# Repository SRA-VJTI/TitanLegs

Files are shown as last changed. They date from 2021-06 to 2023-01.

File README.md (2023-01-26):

# TitanLegs

## Schematics
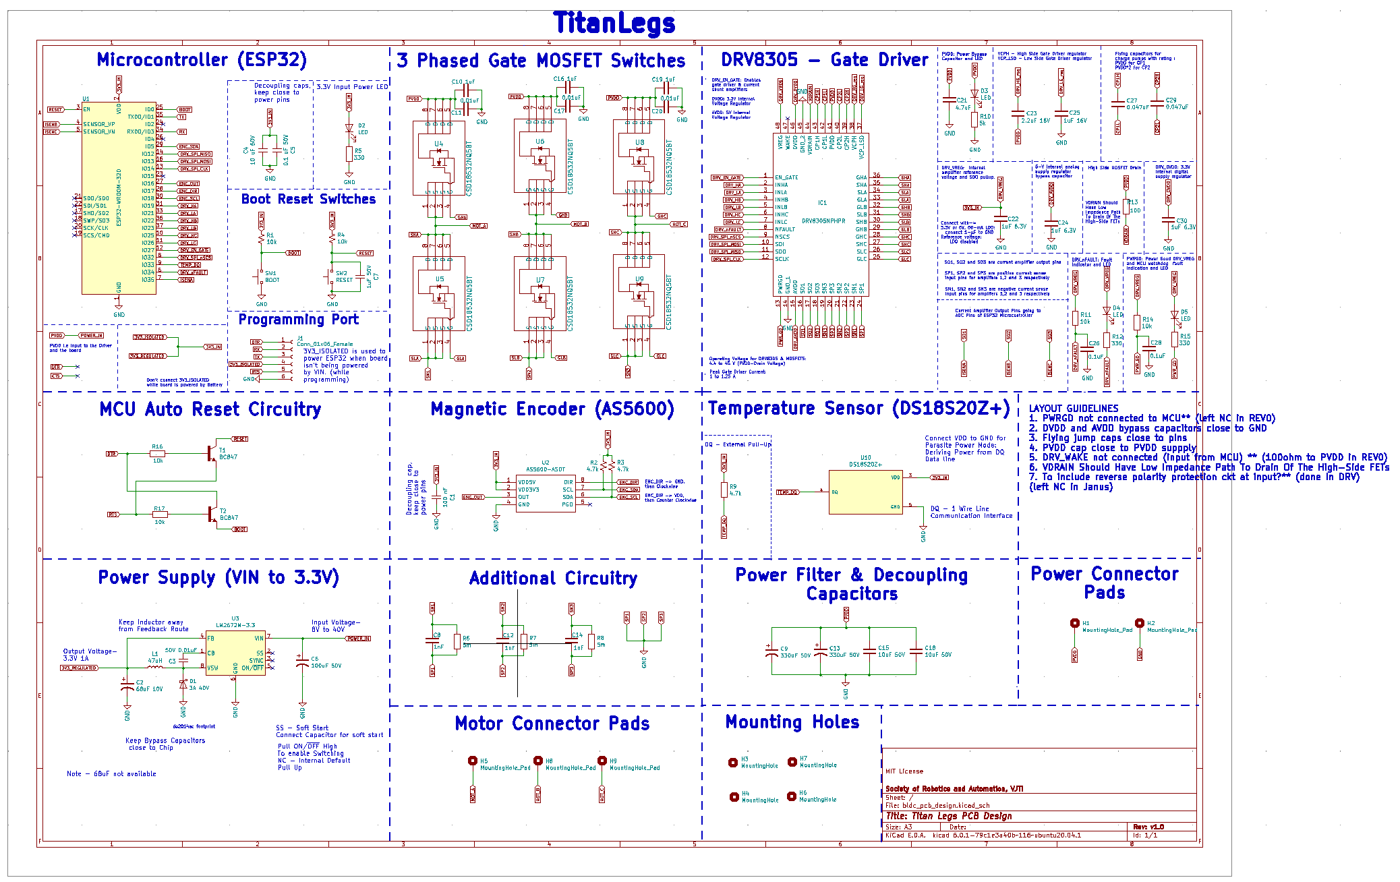
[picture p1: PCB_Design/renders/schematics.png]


## PCB Design
### Front Side
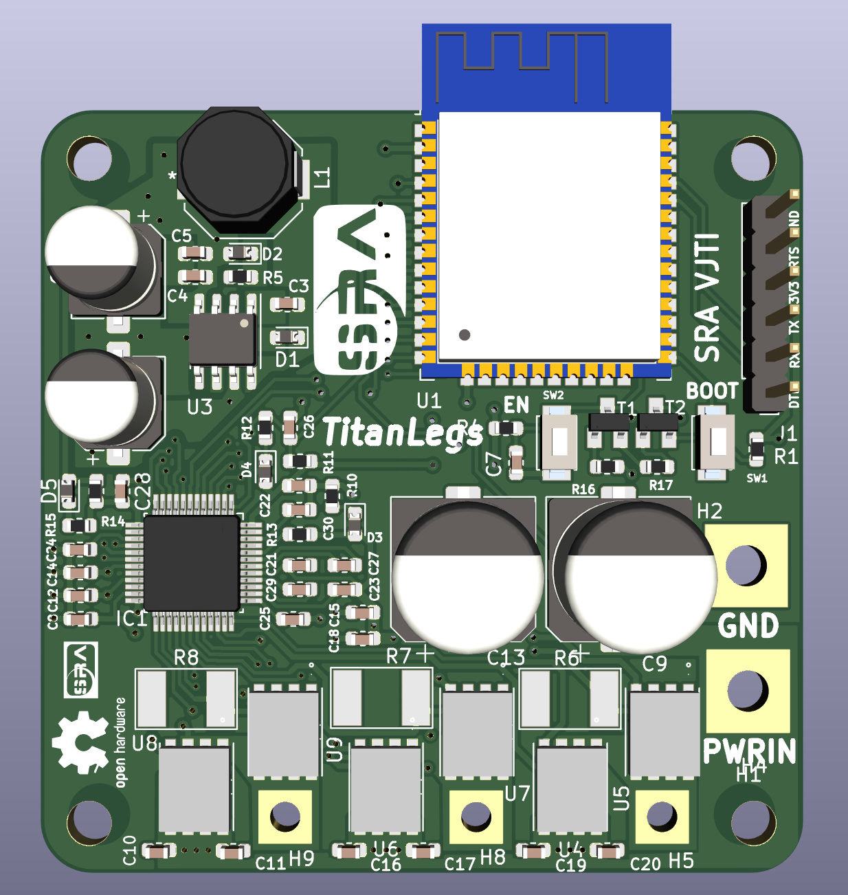
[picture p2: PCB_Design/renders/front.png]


### Back Side
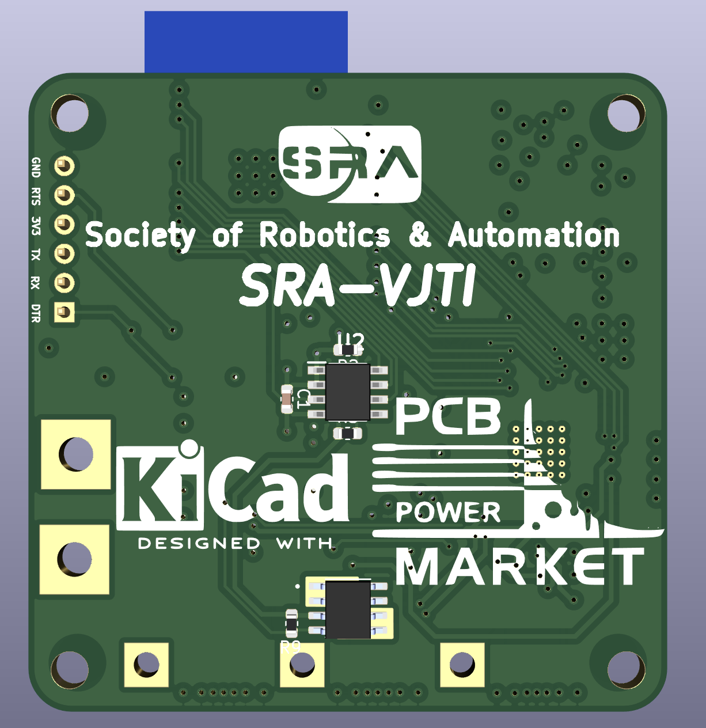
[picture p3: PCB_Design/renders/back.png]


### Routing
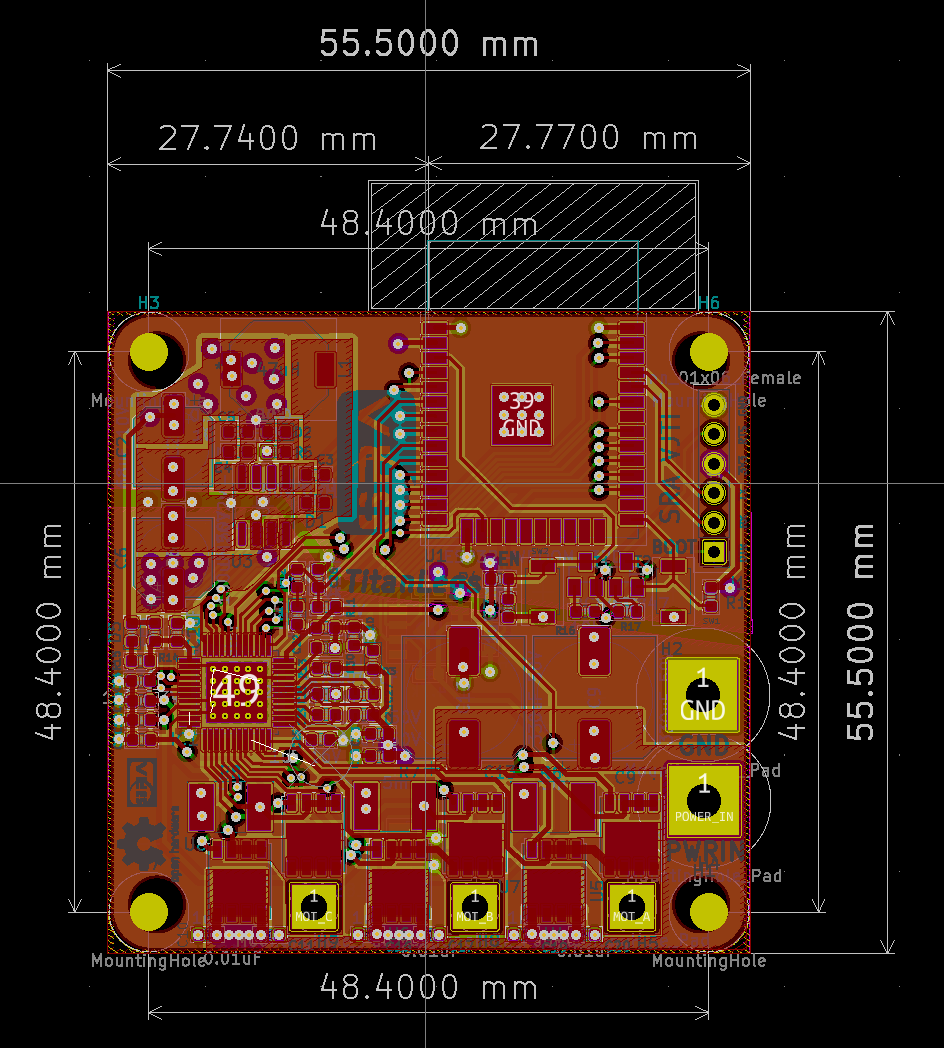
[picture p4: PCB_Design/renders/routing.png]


## TASKS

- [ ] Simulation
  - [ ] Plain Terrain
  - [ ] Rough Terrain
- [ ] Design Actuators
  - [ ] SolidWorks Designing
  - [ ] 3D printing of Legs
  - [ ] Assembling the parts
- [ ] Schematics 
- [ ] Firmware
  - [ ] Actuator
  - [ ] Complete Quadruped

## RESOURCES
* [3D Printed Robot Actuator(hackaday project)](https://hackaday.io/project/157812-3d-printed-robot-actuator)
* [GoGo RC Motor(used in above hackaday project)](https://gogo-rc.com/store/index.php?route=product/product&product_id=3493&search=5010)
* [BLDC Motor Algorithm](https://www.renesas.com/us/en/application/home-building/motor-control-solutions/motor-algorithms/bldc)
* [Python Dynamics Simulation-Part 1](https://medium.com/robotics-devs/python-dynamics-simulations-part-1-f89648a35561)
* [Python BLDC Simulator](https://github.com/gtoonstra/bldc-sim)
* [Gait Analysis of Quadruped](https://cjme.springeropen.com/articles/10.1186/s10033-019-0321-2)
* [Brushless Actuator(Arduino Compatible)](https://hackaday.io/project/165217-brushless-actuator-arduino-compatible)
* [ESP-32 BLDC Robot Actuator Controller](https://hackaday.io/project/169905-esp-32-bldc-robot-actuator-controller)
* [Open Source Motor Control - Odrive](https://odriverobotics.com/)
* [Dynamixel- All in one smart Actuator System](https://www.robotis.us/dynamixel/)
* [Quadruped Simulation on Vrep](http://galvanicloop.com/blog/post/7/quadruped-robot-5-simulation-on-v-rep)
* [Quadruped Robots URDF and Simulation tools](https://github.com/chvmp/champ)
* [Fusion 360 script to export URDF](https://github.com/syuntoku14/fusion2urdf)
* [Another Fusion 360 script to export urdf files](https://github.com/yanshil/Fusion2PyBullet)
* [Onshape- browser based CAD tool](https://onshape-to-robot.readthedocs.io/en/latest/design.html)

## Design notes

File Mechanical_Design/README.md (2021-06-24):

# TABLE OF CONTENTS
- [TitanLegs : Quadruped Actuator](#1)
  - [Gearbox](#2)
- [Resources](#3)

# Titan Legs 

* Quadruped with 2 DoF legs

# Gearbox Design 

* First conceptual prototype of cycloidal gearbox
* Gear reduction ratio used here is 25:1, the same is modelled in the linked assembly with the [Gear Relation](https://cad.onshape.com/help/Content/materelation-gear.htm)
* Modelled in OnShape, you can access the model [here](https://cad.onshape.com/documents/b8c9b425195788ed5b59f624/w/1e0063439de5adffabcff9e9/e/5c14e1911b99b76c077226d1)

<p align="center">
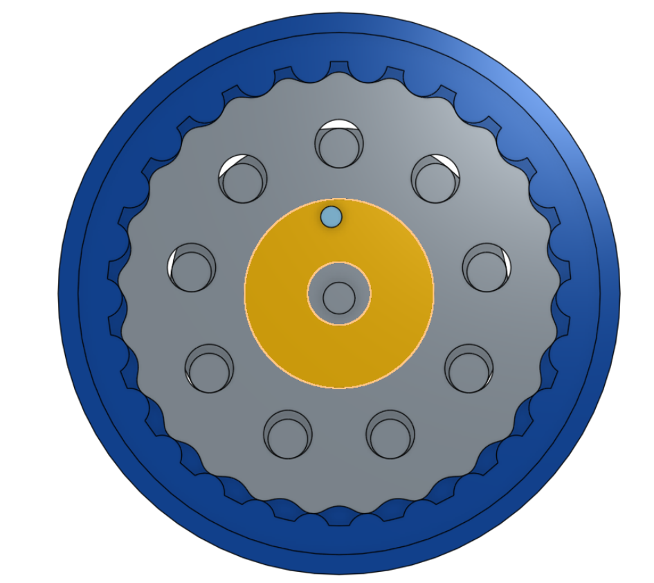
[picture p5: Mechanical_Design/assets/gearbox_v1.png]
  
</p>

# Resources 
* [Cycloidal Drive in Solidworks](https://blogs.solidworks.com/teacher/wp-content/uploads/sites/3/Building-a-Cycloidal-Drive-with-SOLIDWORKS.pdf)
* [Cycloidal gear drive : Design Principles](https://www.irjet.net/archives/V5/i4/IRJET-V5I4565.pdf)

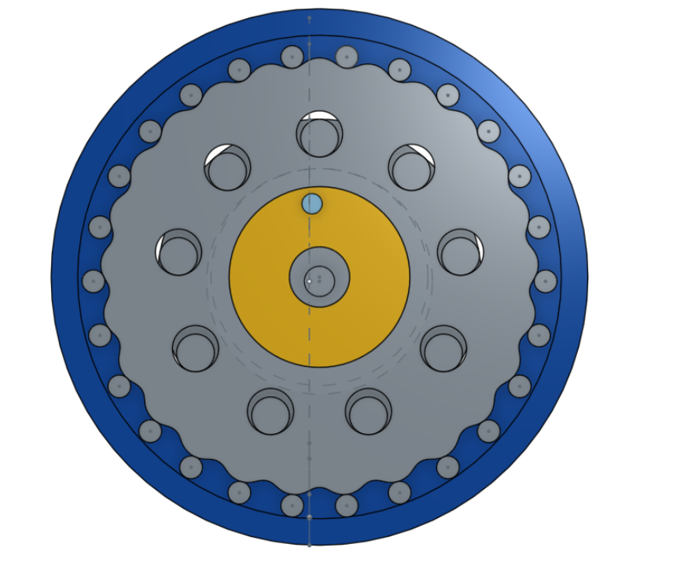
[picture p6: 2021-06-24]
Mechanical_Design/assets/gearbox_v0.png

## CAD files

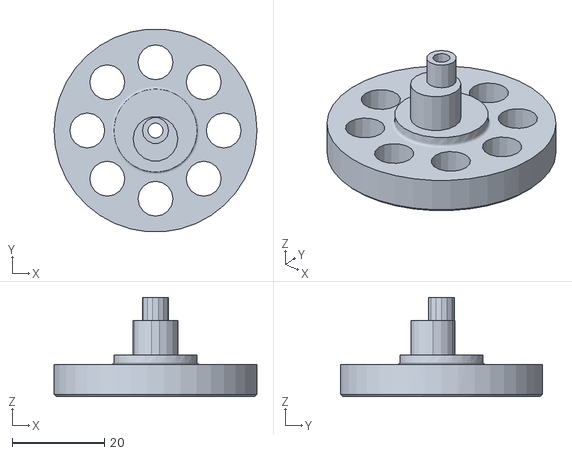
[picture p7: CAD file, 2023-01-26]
Mechanical_Design/Gearbox_STL/Mediator_out.STL
44.0 x 43.8 x 21.5

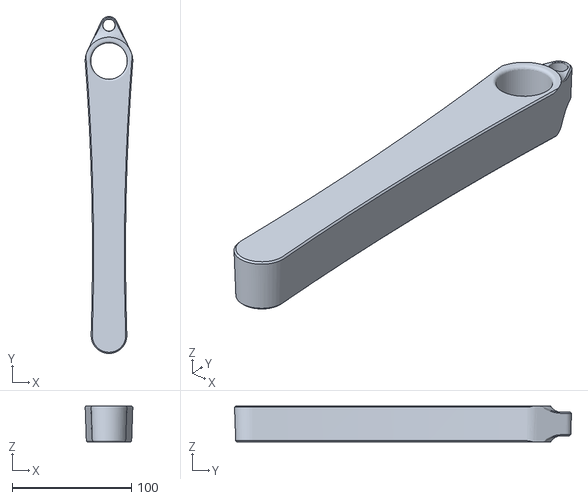
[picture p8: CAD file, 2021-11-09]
Mechanical_Design/Leg_Design/3_Lower_Limb.STL
39.9 x 282.3 x 30.0

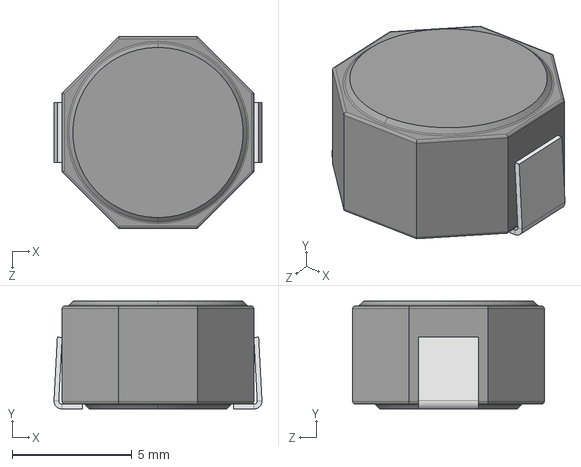
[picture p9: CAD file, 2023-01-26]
PCB_Design/bldc_pcb_design/component_libraries/8D43_Inductor/8D43.step
8.69 x 4.50 x 8.00 mm

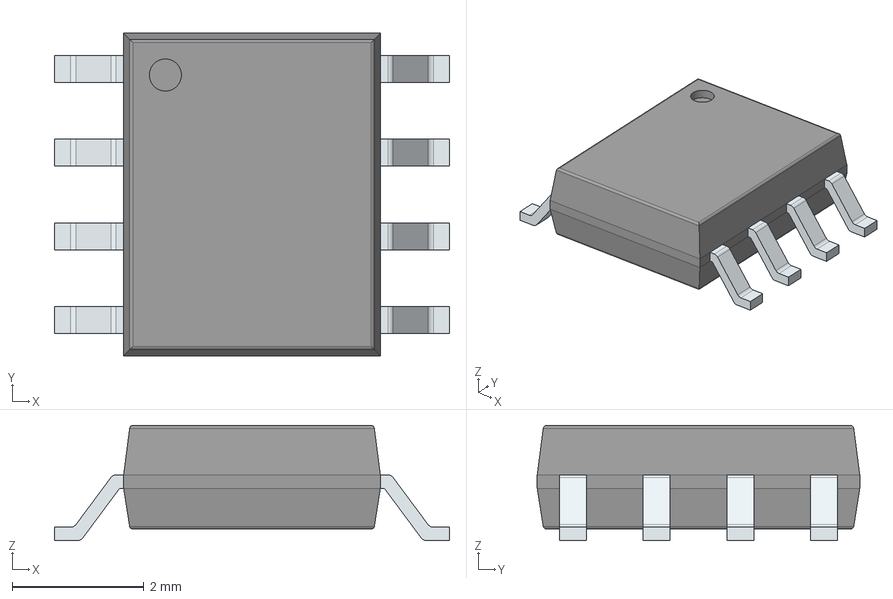
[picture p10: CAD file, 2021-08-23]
PCB_Design/bldc_pcb_design/component_libraries/AS5600/AS5600-ASOT.stp
6.00 x 4.90 x 1.75 mm
PinsArrayLR

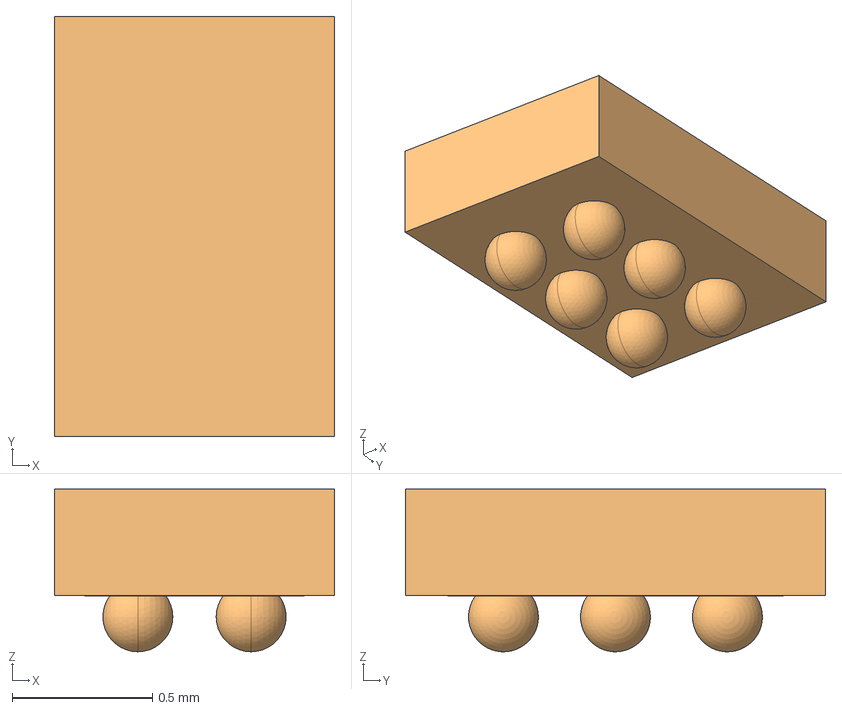
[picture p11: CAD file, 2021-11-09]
PCB_Design/bldc_pcb_design/component_libraries/AS6200-AWLT-S/AS6200.step
1 x 1.50 x 0.581 mm

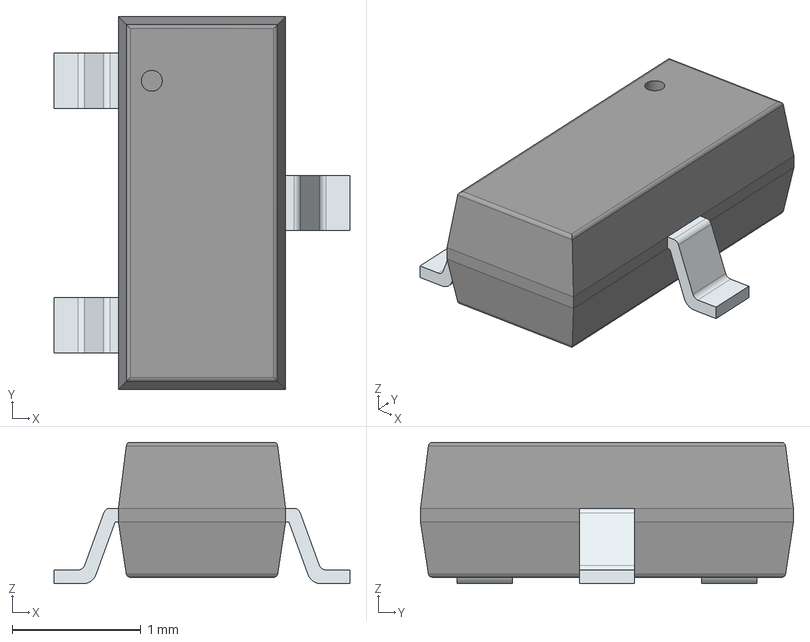
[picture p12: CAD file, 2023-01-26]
PCB_Design/bldc_pcb_design/component_libraries/BC847/BC847.stp
2.30 x 2.90 x 1.10 mm
PinsArrayL
FilletPinR

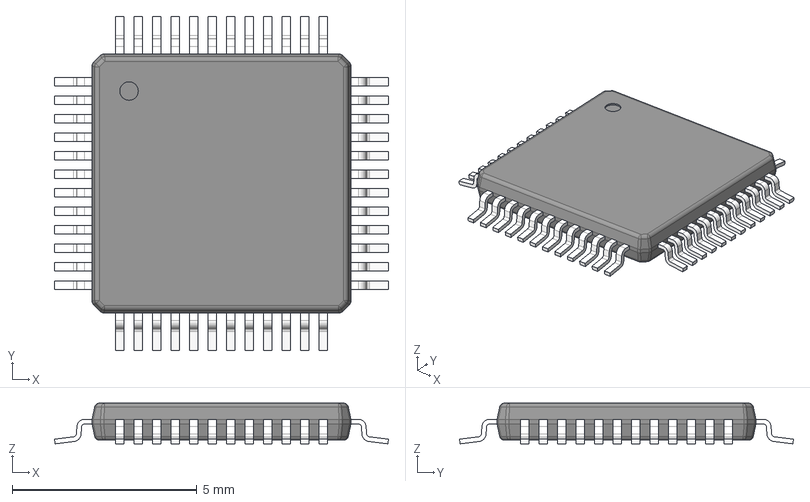
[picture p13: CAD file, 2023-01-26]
PCB_Design/bldc_pcb_design/component_libraries/DRV8305NPHPR/DRV8305NPHPR.stp
9.03 x 9.03 x 1.10 mm
BODY-QFP
LEAD-QFP x 48
THERMALPAD-PHP0048G

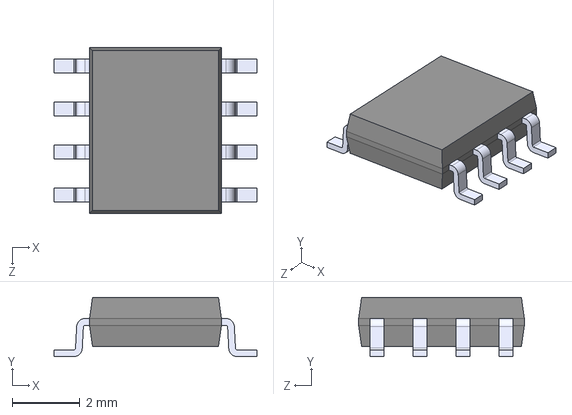
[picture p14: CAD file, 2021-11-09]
PCB_Design/bldc_pcb_design/component_libraries/DS18S20Z_/DS18S20Z_.step
6.00 x 1.75 x 4.90 mm

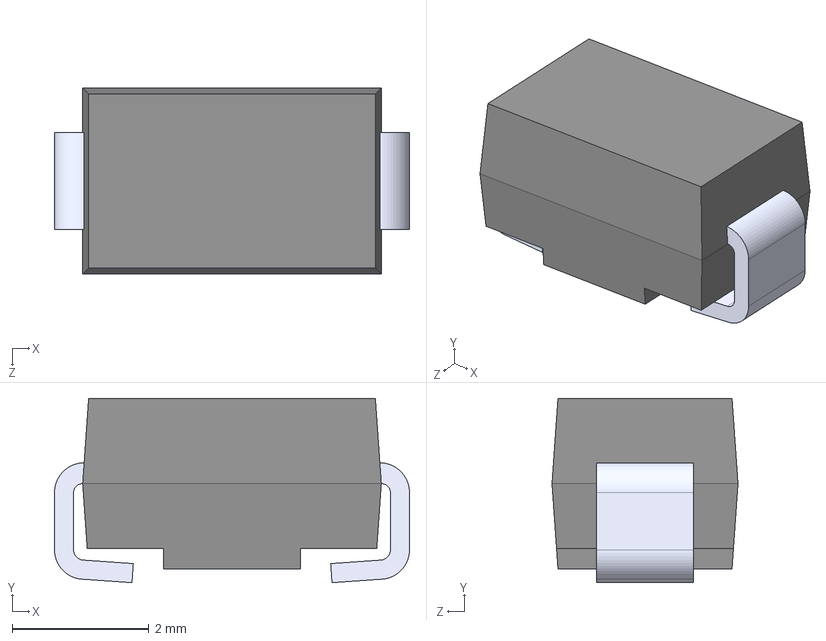
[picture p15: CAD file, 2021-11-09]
PCB_Design/bldc_pcb_design/component_libraries/SS34_Diode/SS34.step
5.20 x 2.70 x 2.73 mm

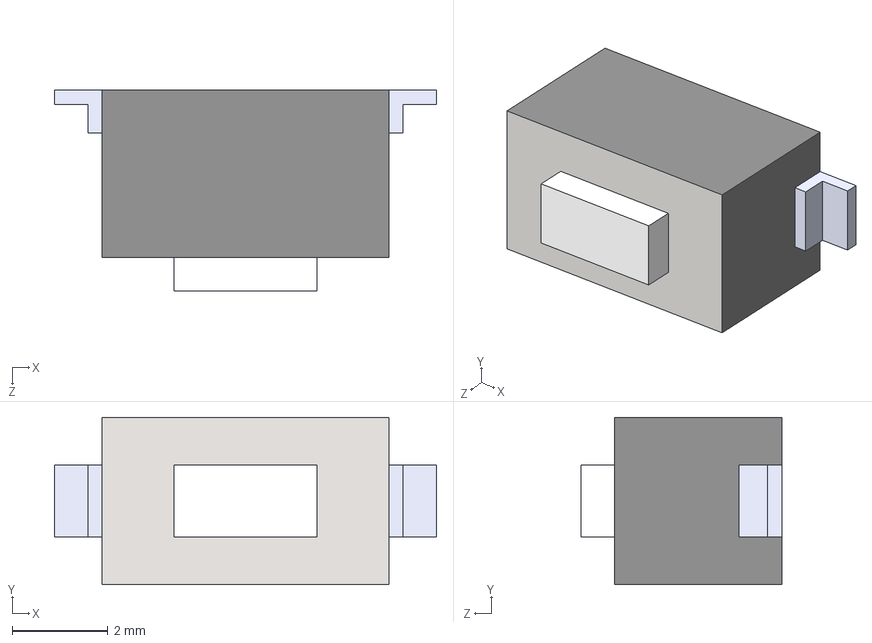
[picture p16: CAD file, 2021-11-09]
PCB_Design/bldc_pcb_design/component_libraries/Tactile_Switch/Tactile_Switch.STEP
8.00 x 3.50 x 4.20 mm

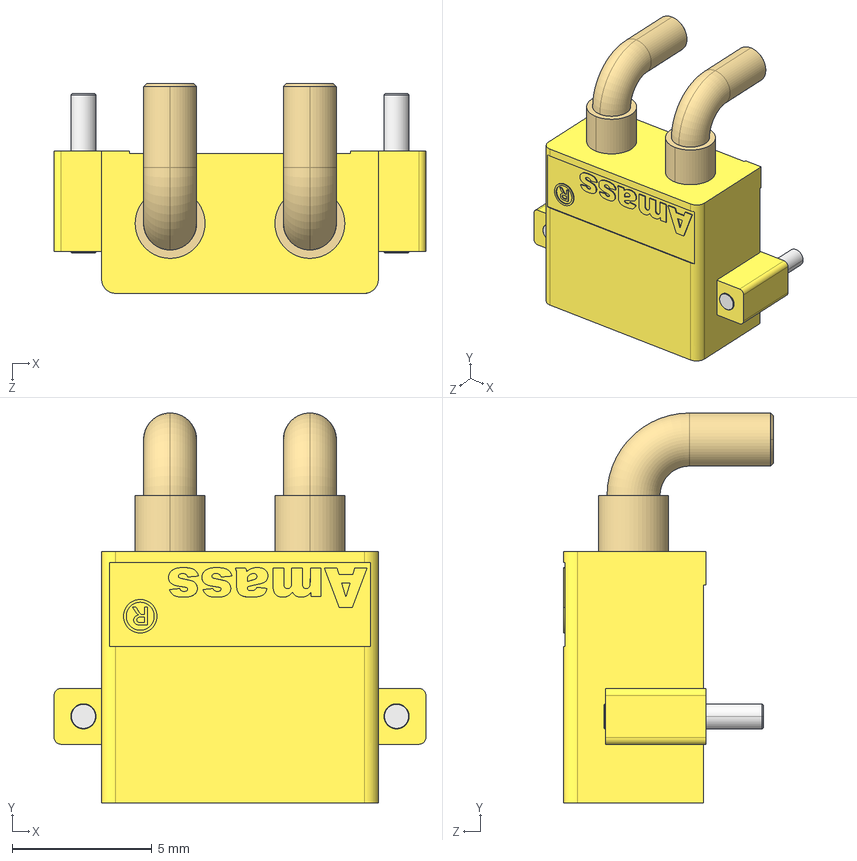
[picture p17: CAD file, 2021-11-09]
PCB_Design/bldc_pcb_design/component_libraries/XT30PW-M/XT30PW-M.stp
13.3 x 13.9 x 7.50 mm

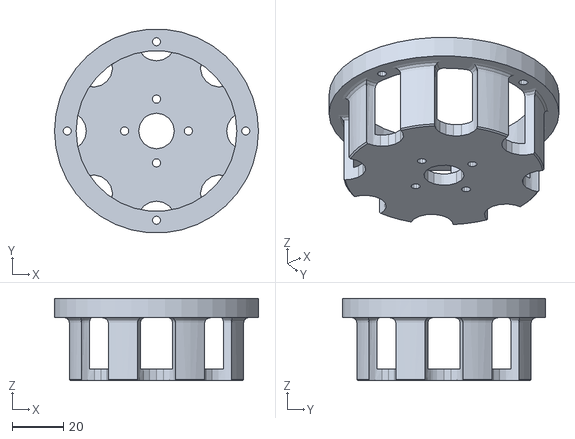
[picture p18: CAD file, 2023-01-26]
Mechanical_Design/Gearbox_STL/Motor_Cover.STL
80.0 x 79.7 x 32.3

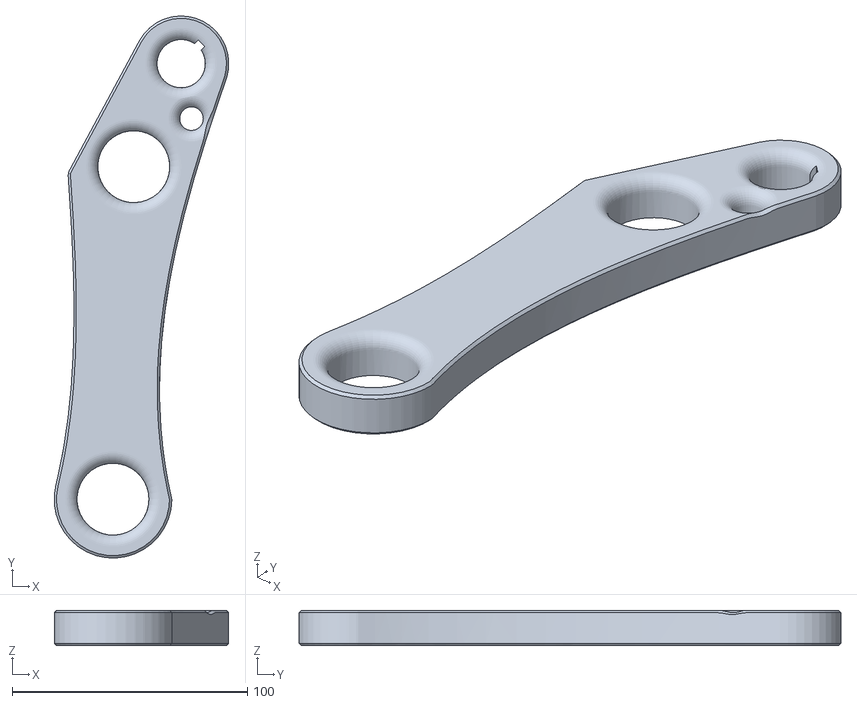
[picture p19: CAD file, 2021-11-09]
Mechanical_Design/Leg_Design/1_Lower_Limb_Connector.STL
74.1 x 230.2 x 15.0

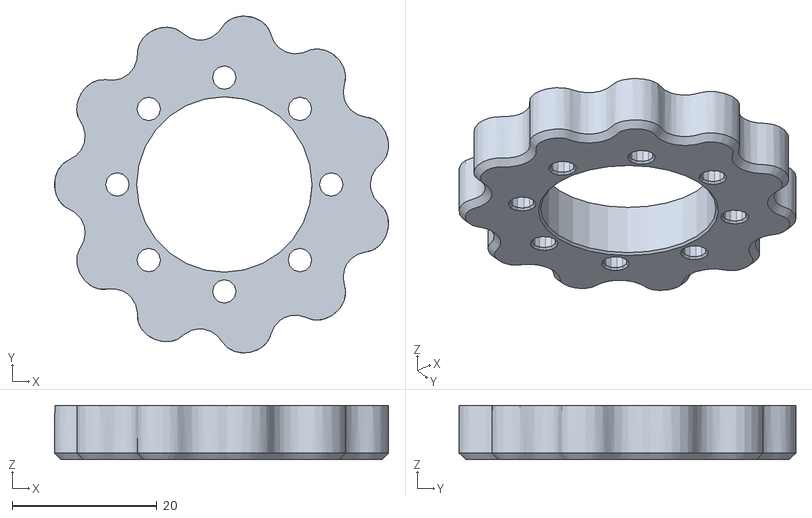
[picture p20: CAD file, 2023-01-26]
Mechanical_Design/Gearbox_STL/Rotor_11.STL
46.2 x 46.6 x 7.50

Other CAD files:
Mechanical_Design/Leg_Design/2_Upper_Limb_Connector.STL
Mechanical_Design/Gearbox_STL/Out_Box.STL
Mechanical_Design/Leg_Design/6_Wire_Clamp_Bottom.STL
Mechanical_Design/Gearbox_STL/Combined_Box.STL
Mechanical_Design/Gearbox_STL/New_Shaft_1.STL
Mechanical_Design/Gearbox_STL/New_shaft_2.STL
Mechanical_Design/Gearbox_STL/Output_Disk.STL
Mechanical_Design/Gearbox_STL/Rotor_10.STL
Mechanical_Design/Leg_Design/4_3D_Nut.STL
Mechanical_Design/Leg_Design/5_Wire_Clamp_Top.STL
PCB_Design/bldc_pcb_design/component_libraries/BC847/BC847.stl
PCB_Design/bldc_pcb_design/component_libraries/CSD18532NQ5B/CSD18532NQ5B.stp

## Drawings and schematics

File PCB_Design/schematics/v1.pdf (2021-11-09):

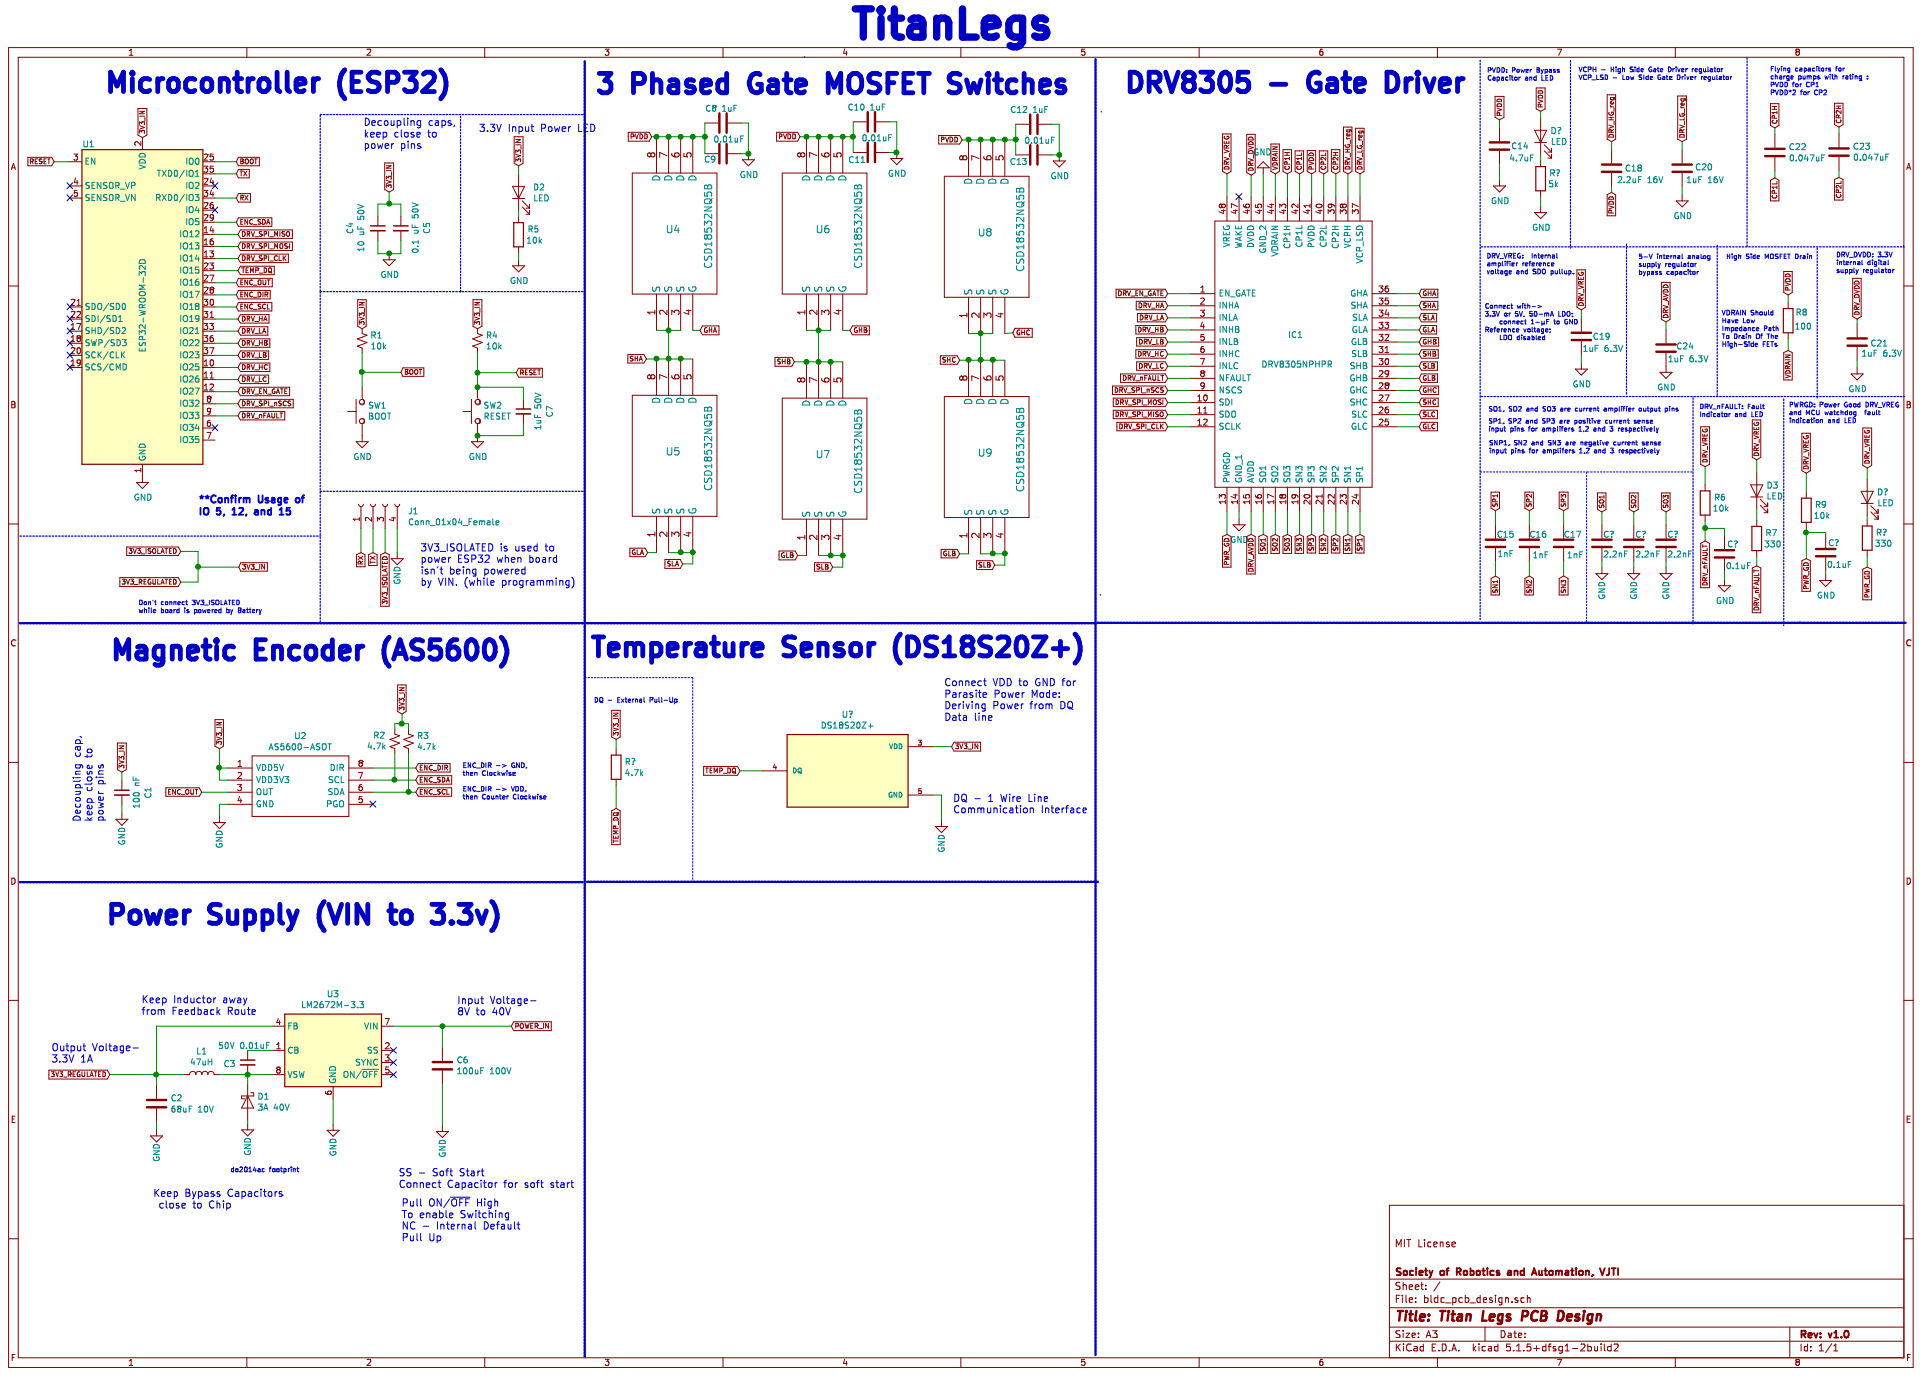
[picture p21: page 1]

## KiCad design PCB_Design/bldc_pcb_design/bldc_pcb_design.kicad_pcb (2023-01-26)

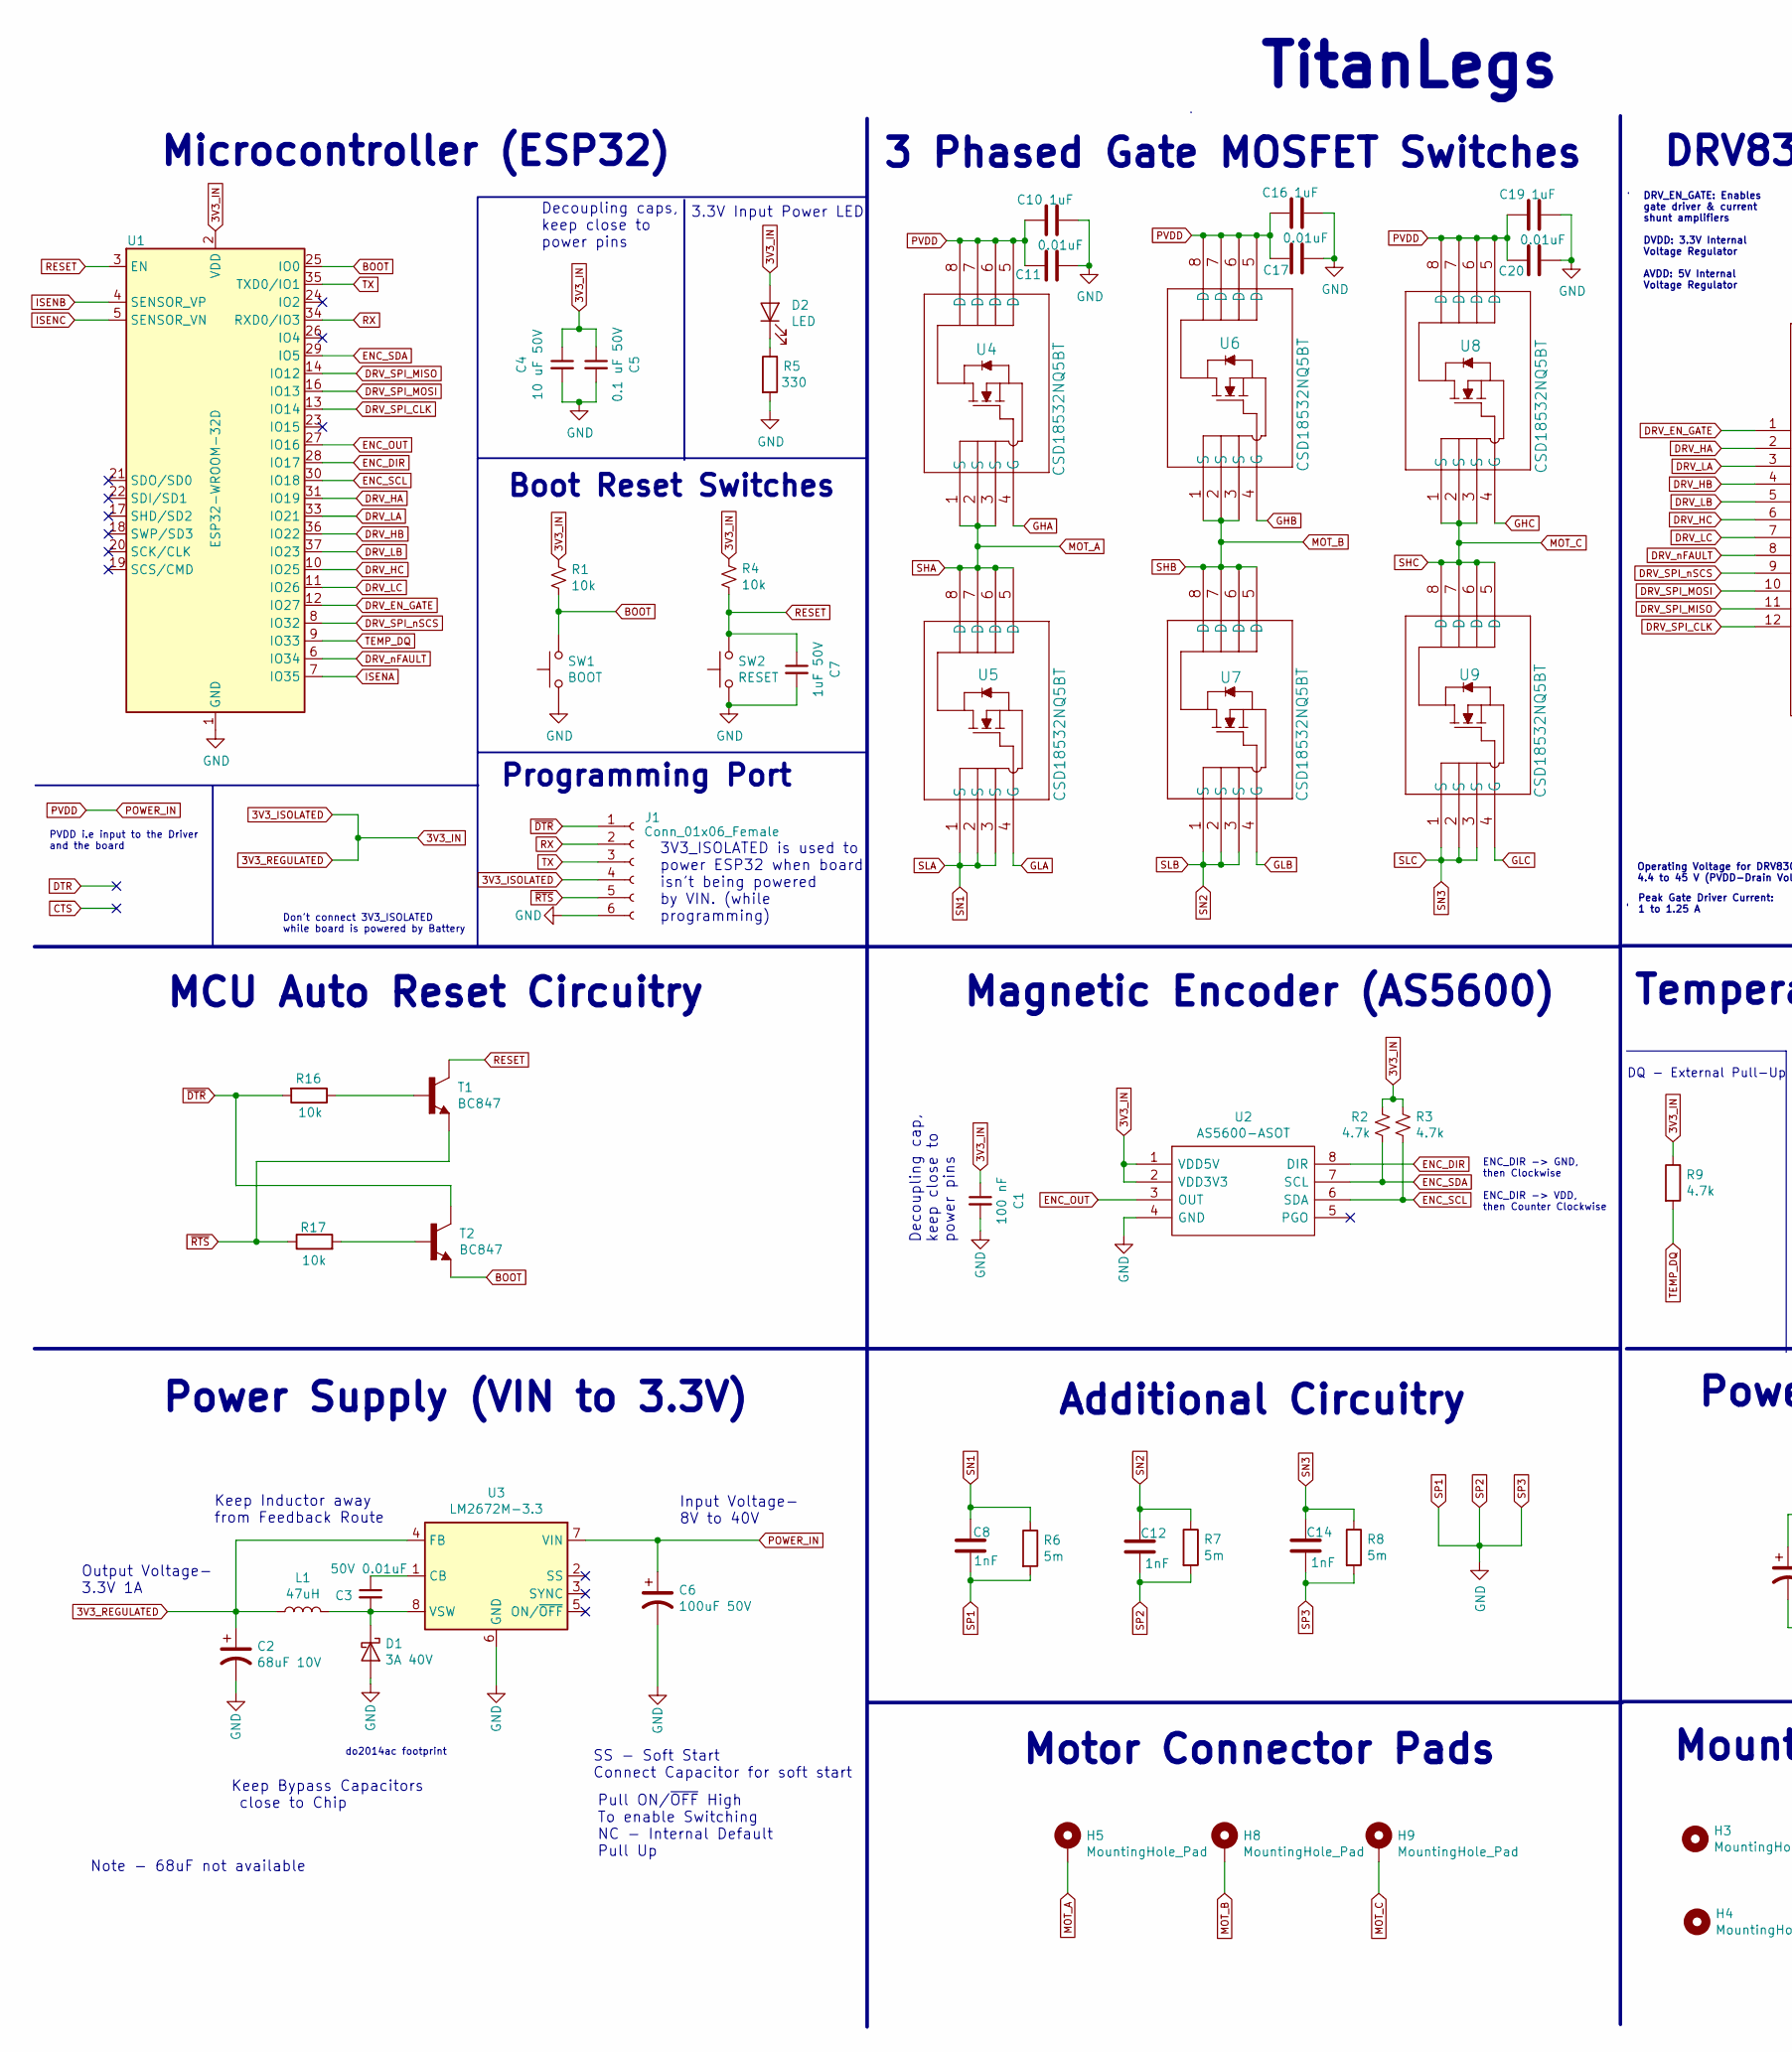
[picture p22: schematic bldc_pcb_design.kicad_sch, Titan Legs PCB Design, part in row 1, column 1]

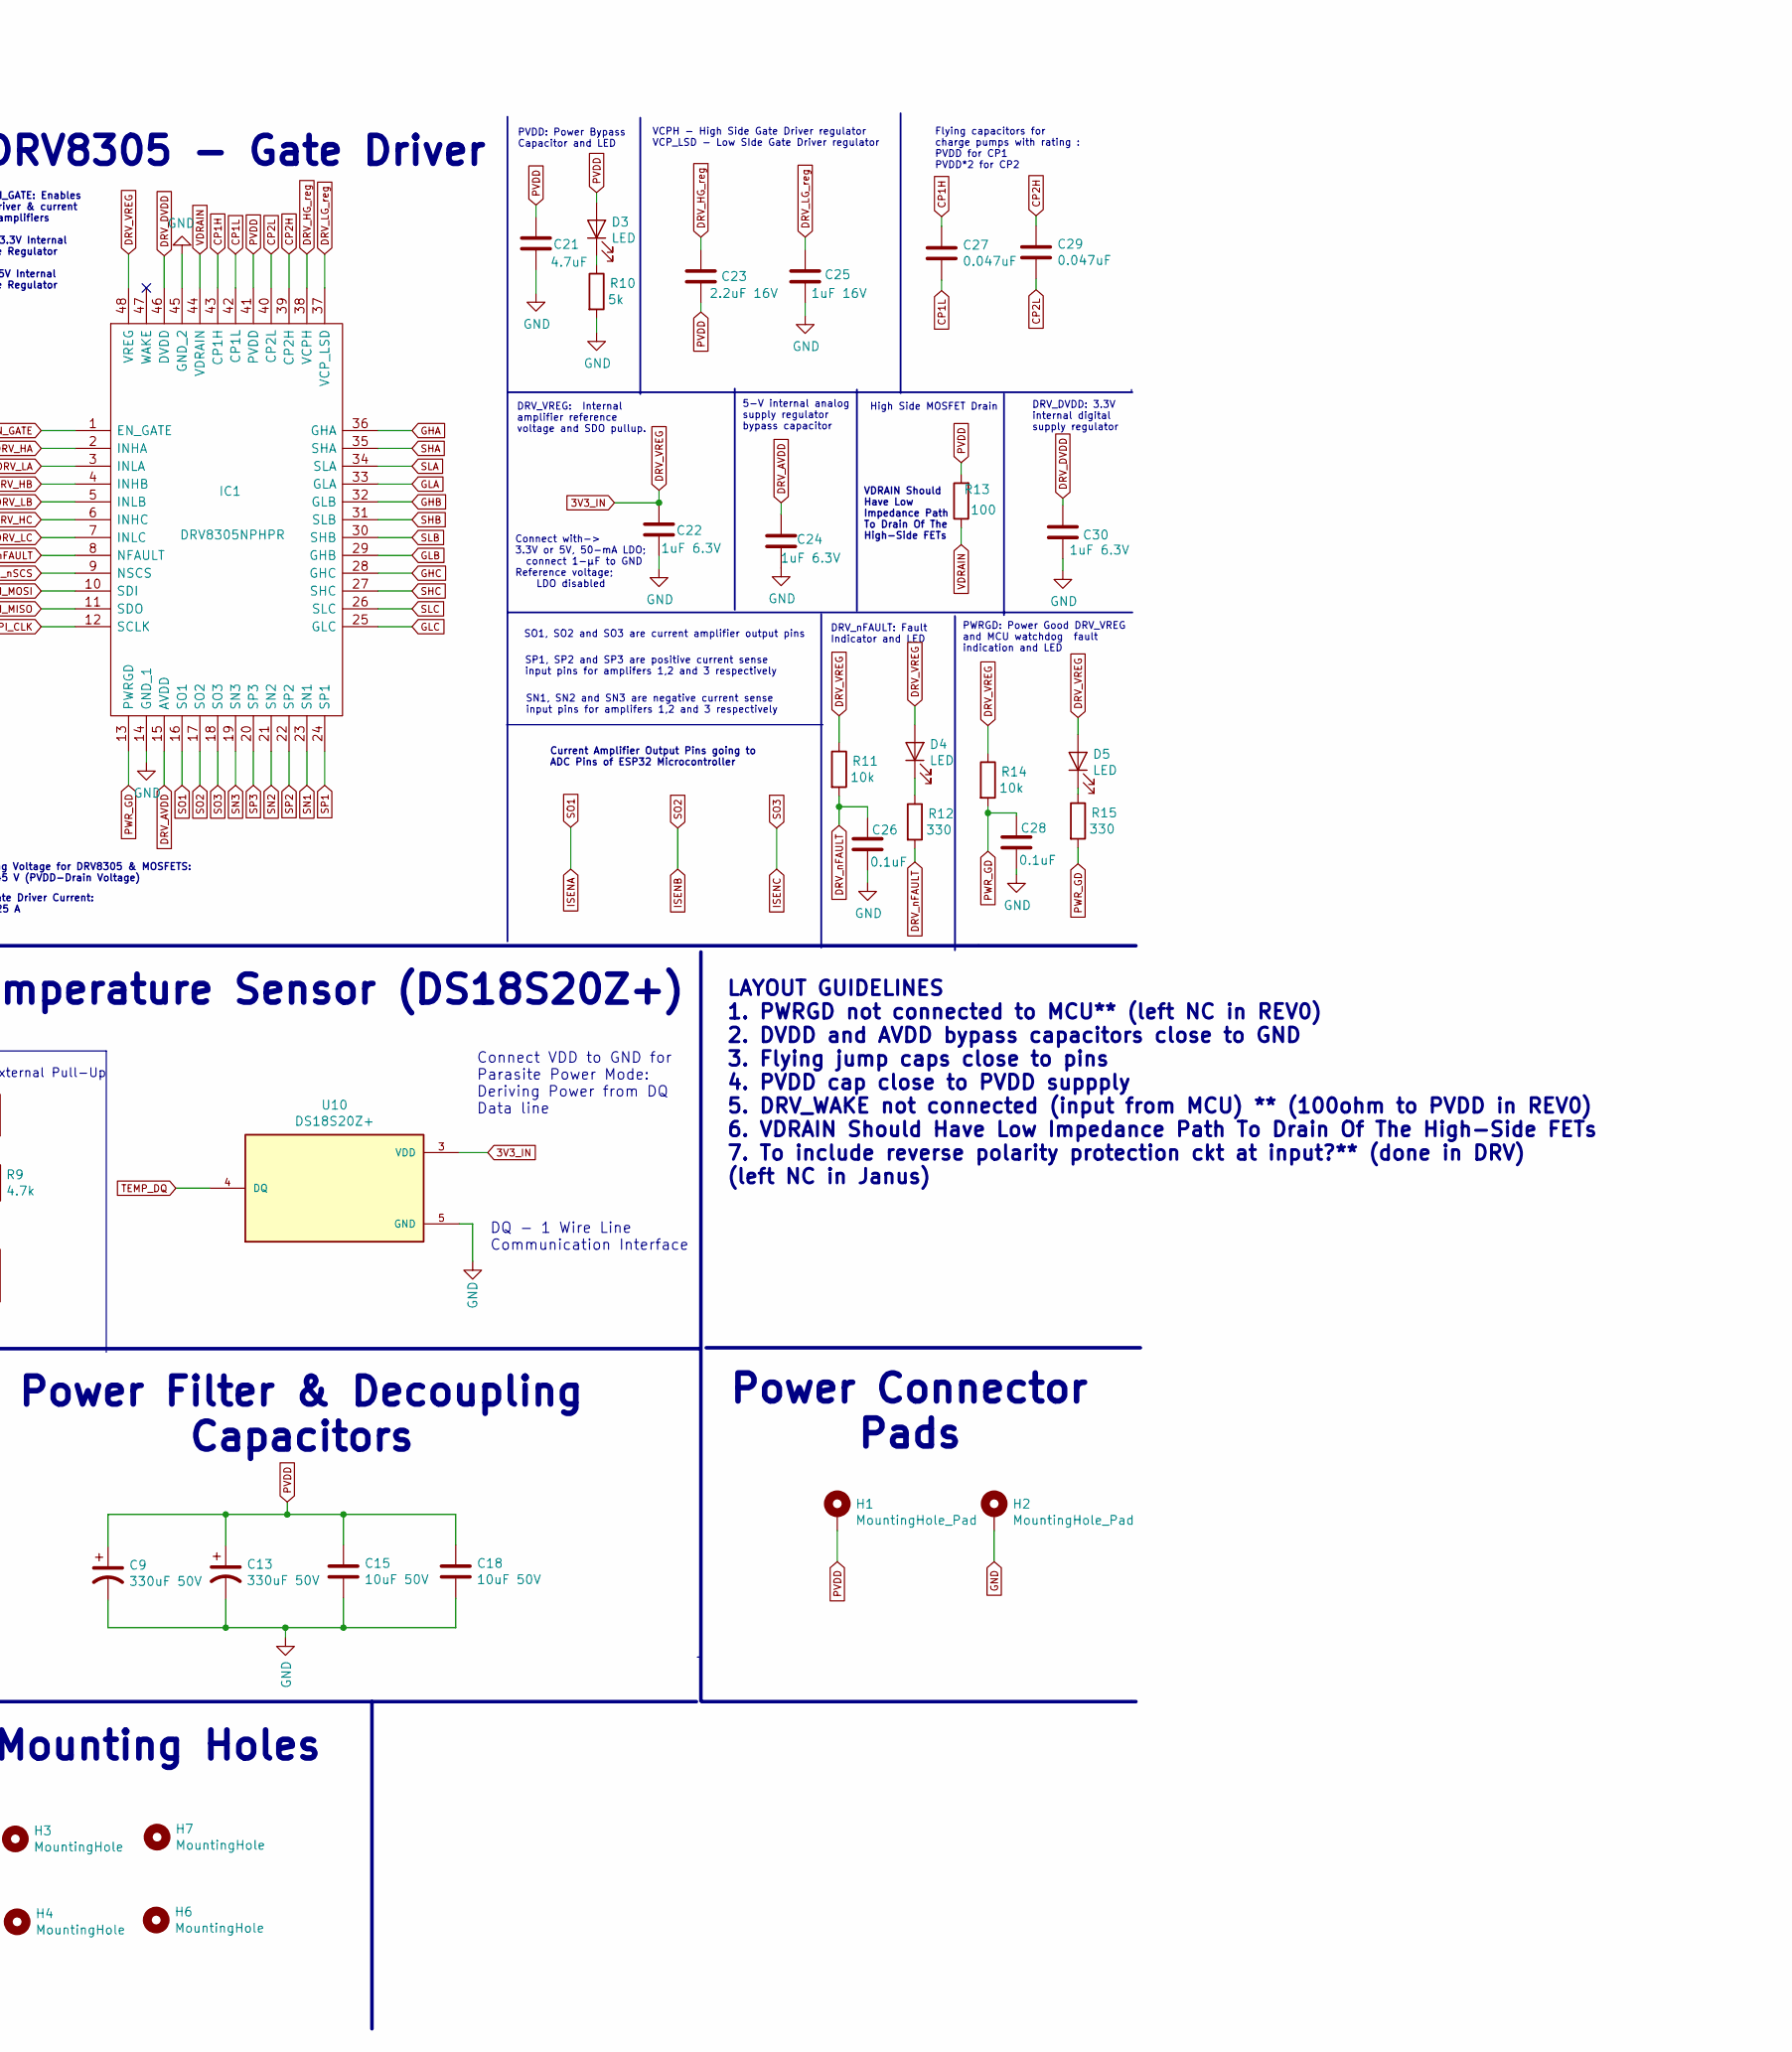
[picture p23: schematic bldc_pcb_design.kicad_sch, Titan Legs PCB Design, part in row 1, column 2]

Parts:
C1: 100 nF; C_0603_1608Metric
C2: 68uF 10V; CP_Elec_6.3x7.7
C3: 50V 0.01uF; C_0603_1608Metric
C4: 10 uF 50V; C_0603_1608Metric
C5: 0.1 uF 50V; C_0603_1608Metric
C6: 100uF 50V; CP_Elec_6.3x7.7
C7: 1uF 50V; C_0603_1608Metric
C8, C12, C14: 1nF; C_0603_1608Metric
C9, C13: 330uF 50V; CP_Elec_10x10
C10, C16, C19: 1uF; C_0603_1608Metric
C11, C17, C20: 0.01uF; C_0603_1608Metric
C15, C18: 10uF 50V; C_0603_1608Metric
C21: 4.7uF; C_0603_1608Metric
C22, C24, C30: 1uF 6.3V; C_0603_1608Metric
C23: 2.2uF 16V; C_0603_1608Metric
C25: 1uF 16V; C_0603_1608Metric
C26, C28: 0.1uF; C_0603_1608Metric
C27, C29: 0.047uF; C_0603_1608Metric
D1: 3A 40V; D_0603_1608Metric
D2, D3, D4, D5: LED; D_0603_1608Metric
H1, H2: MountingHole_Pad; MountingHole_6.4mm_M6_DIN965_Pad
H3, H4, H6, H7: MountingHole; MountingHole_3.2mm_M3
H5, H8, H9: MountingHole_Pad; MountingHole_2.2mm_M2_DIN965_Pad
IC1: DRV8305NPHPR; DRV8305NEPHPRQ1_with_GND_pads; Manufacturer_Part_Number DRV8305NPHPR; Mouser Part Number 595-DRV8305NPHPR
J1: Conn_01x06_Female; PinHeader_1x06_P2.54mm_Vertical
L1: 47uH; 8D43
R1, R4, R11, R14, R16, R17: 10k; R_0603_1608Metric
R2, R3, R9: 4.7k; R_0603_1608Metric
R5, R12, R15: 330; R_0603_1608Metric
R6, R7, R8: 5m; Shunt_Resistor_L7.0mm_B4.0mm_H1.0mm
R10: 5k; R_0603_1608Metric
R13: 100; R_0603_1608Metric
SW1: BOOT; Tactile_Switch
SW2: RESET; Tactile_Switch
T1, T2: BC847
U1: ESP32-WROOM-32D; ESP32-WROOM-32
U2: AS5600-ASOT; AS5600; Manufacturer_Part_Number AS5600-ASOT; Mouser Part Number 985-AS5600-ASOT
U3: LM2672M-3.3; SOIC-8_3.9x4.9mm_P1.27mm
U4, U5, U6, U7, U8, U9: CSD18532NQ5BT; CSD18532NQ5B
U10: DS18S20Z+; DS18S20Z_; PARTREV 3

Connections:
3V3_IN: C1.1, C2.1, C4.1, C5.1, C22.2, D2.2 (A), D4.2 (A), D5.2 (A), IC1.48 (VREG), J1.4, L1.1, R1.1, R2.2, R3.1, R4.1, R9.1, R11.1, R14.1, U1.2 (VDD), U2.1 (VDD5V), U2.2 (VDD3V3), U3.4 (FB), U10.3 (VDD)
BOOT: R1.2, SW1.2, T2.2, U1.25 (IO0)
CP1H: C27.1, IC1.43 (CP1H)
CP1L: C27.2, IC1.42 (CP1L)
CP2H: C29.1, IC1.39 (CP2H)
CP2L: C29.2, IC1.40 (CP2L)
DRV_AVDD: C24.2, IC1.15 (AVDD)
DRV_DVDD: C30.2, IC1.46 (DVDD)
DRV_EN_GATE: IC1.1 (EN_GATE), U1.12 (IO27)
DRV_HA: IC1.2 (INHA), U1.31 (IO19)
DRV_HB: IC1.4 (INHB), U1.36 (IO22)
DRV_HC: IC1.6 (INHC), U1.10 (IO25)
DRV_HG_reg: C23.1, IC1.38 (VCPH)
DRV_LA: IC1.3 (INLA), U1.33 (IO21)
DRV_LB: IC1.5 (INLB), U1.37 (IO23)
DRV_LC: IC1.7 (INLC), U1.11 (IO26)
DRV_LG_reg: C25.1, IC1.37 (VCP_LSD)
DRV_SPI_CLK: IC1.12 (SCLK), U1.13 (IO14)
DRV_SPI_MISO: IC1.11 (SDO), U1.14 (IO12)
DRV_SPI_MOSI: IC1.10 (SDI), U1.16 (IO13)
DRV_SPI_nSCS: IC1.9 (NSCS), U1.8 (IO32)
DRV_nFAULT: C26.1, IC1.8 (NFAULT), R11.2, R12.2, U1.6 (IO34)
ENC_DIR: U1.28 (IO17), U2.8 (DIR)
ENC_OUT: U1.27 (IO16), U2.3 (OUT)
ENC_SCL: R3.2, U1.30 (IO18), U2.6 (SDA)
ENC_SDA: R2.1, U1.29 (IO5), U2.7 (SCL)
GHA: IC1.36 (GHA), U4.4 (G)
GHB: IC1.32 (GLB), U6.4 (G)
GHC: IC1.28 (GHC), U8.4 (G)
GLA: IC1.33 (GLA), U5.4 (G)
GLB: IC1.29 (GHB), U7.4 (G)
GLC: IC1.25 (GLC), U9.4 (G)
GND: C1.2, C2.2, C4.2, C5.2, C6.2, C7.2, C8.2, C9.2, C10.2, C11.2, C12.2, C13.2, C14.2, C15.2, C16.2, C17.2, C18.2, C19.2, C20.2, C21.1, C22.1, C24.1, C25.2, C26.2, C28.2, C30.1, D1.2 (A), H2.1, IC1.14 (GND_1), IC1.20 (SP3), IC1.22 (SP2), IC1.24 (SP1), IC1.45 (GND_2), J1.6, R5.2, R6.2, R7.2, R8.2, R10.2, SW1.1, SW2.1, U1.1 (GND), U1.15 (GND), U1.38 (GND), U1.39 (GND), U2.4 (GND), U3.6 (GND), U10.5 (GND)
ISENA: IC1.16 (SO1), U1.7 (IO35)
ISENB: IC1.17 (SO2), U1.4 (SENSOR_VP)
ISENC: IC1.18 (SO3), U1.5 (SENSOR_VN)
MOT_A: H5.1, IC1.35 (SHA), U4.1 (S), U4.2 (S), U4.3 (S), U5.5 (D), U5.6 (D), U5.7 (D), U5.8 (D)
MOT_B: H8.1, IC1.31 (SLB), U6.1 (S), U6.2 (S), U6.3 (S), U7.5 (D), U7.6 (D), U7.7 (D), U7.8 (D)
MOT_C: H9.1, IC1.27 (SHC), U8.1 (S), U8.2 (S), U8.3 (S), U9.5 (D), U9.6 (D), U9.7 (D), U9.8 (D)
unnamed: C3.1, U3.1 (CB)
unnamed: C3.2, D1.1 (K), L1.2, U3.8 (VSW)
unnamed: D2.1 (K), R5.1
unnamed: D3.1 (K), R10.1
unnamed: D4.1 (K), R12.1
unnamed: D5.1 (K), R15.1
unnamed: R16.1, T1.1
unnamed: R17.2, T2.1
POWER_IN: C6.1, C9.1, C10.1, C11.1, C13.1, C15.1, C16.1, C17.1, C18.1, C19.1, C20.1, C21.2, C23.2, D3.2 (A), H1.1, IC1.41 (PVDD), R13.2, U3.7 (VIN), U4.5 (D), U4.6 (D), U4.7 (D), U4.8 (D), U6.5 (D), U6.6 (D), U6.7 (D), U6.8 (D), U8.5 (D), U8.6 (D), U8.7 (D), U8.8 (D)
PWR_GD: C28.1, IC1.13 (PWRGD), R14.2, R15.2
RESET: C7.1, R4.2, SW2.2, T1.3, U1.3 (EN)
RX: J1.2, U1.34 (RXD0/IO3)
SLA: C8.1, IC1.23 (SN1), IC1.34 (SLA), R6.1, U5.1 (S), U5.2 (S), U5.3 (S)
SLB: C12.1, IC1.21 (SN2), IC1.30 (SHB), R7.1, U7.1 (S), U7.2 (S), U7.3 (S)
SLC: C14.1, IC1.19 (SN3), IC1.26 (SLC), R8.1, U9.1 (S), U9.2 (S), U9.3 (S)
TEMP_DQ: R9.2, U1.9 (IO33), U10.4 (DQ)
TX: J1.3, U1.35 (TXD0/IO1)
VDRAIN: IC1.44 (VDRAIN), R13.1
~DTR: J1.1, R16.2, T2.3
~RTS: J1.5, R17.1, T1.2

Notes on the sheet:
ENC_DIR -> GND, then Clockwise ENC_DIR -> VDD, then Counter Clockwise
Power Connector Pads
Programming Port
DQ - 1 Wire Line Communication Interface
5-V internal analog supply regulator bypass capacitor
Output Voltage- 3.3V 1A
do2014ac footprint
PWRGD: Power Good DRV_VREG and MCU watchdog fault indication and LED
DRV_DVDD: 3.3V internal digital supply regulator
DQ - External Pull-Up
Peak Gate Driver Current: 1 to 1.25 A
LAYOUT GUIDELINES 1. PWRGD not connected to MCU** (left NC in REV0) 2. DVDD and AVDD bypass capacitors close to GND 3. Flying jump caps close to pins 4. PVDD cap close to PVDD suppply 5. DRV_WAKE not connected (input from MCU) ** (100ohm to PVDD in REV0) 6. VDRAIN Should Have Low Impedance Path To 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
Note - 68uF not available
SN1, SN2 and SN3 are negative current sense input pins for amplifers 1,2 and 3 respectively
Operating Voltage for DRV8305 & MOSFETS: 4.4 to 45 V (PVDD-Drain Voltage)
SS - Soft Start Connect Capacitor for soft start
Additional Circuitry
SO1, SO2 and SO3 are current amplifier output pins
Current Amplifier Output Pins going to ADC Pins of ESP32 Microcontroller
Don't connect 3V3_ISOLATED while board is powered by Battery
3V3_ISOLATED is used to power ESP32 when board isn't being powered by VIN. (while programming)
DRV_VREG: Internal amplifier reference voltage and SDO pullup.
High Side MOSFET Drain
Connect VDD to GND for Parasite Power Mode: Deriving Power from DQ Data line
Power Supply (VIN to 3.3V)
Temperature Sensor (DS18S20Z+)
SP1, SP2 and SP3 are positive current sense input pins for amplifers 1,2 and 3 respectively
VDRAIN Should Have Low Impedance Path To Drain Of The High-Side FETs
Boot Reset Switches
DRV_EN_GATE: Enables gate driver & current shunt amplifiers DVDD: 3.3V Internal Voltage Regulator AVDD: 5V Internal Voltage Regulator
DRV_nFAULT: Fault Indicator and LED
Pull ON/~{OFF} High To enable Switching NC - Internal Default Pull Up
Flying capacitors for charge pumps with rating : PVDD for CP1 PVDD*2 for CP2
Microcontroller (ESP32)
Keep Bypass Capacitors close to Chip
Mounting Holes
PVDD i.e input to the Driver and the board
TitanLegs
Decoupling cap, keep close to power pins
VCPH - High Side Gate Driver regulator VCP_LSD - Low SIde Gate Driver regulator

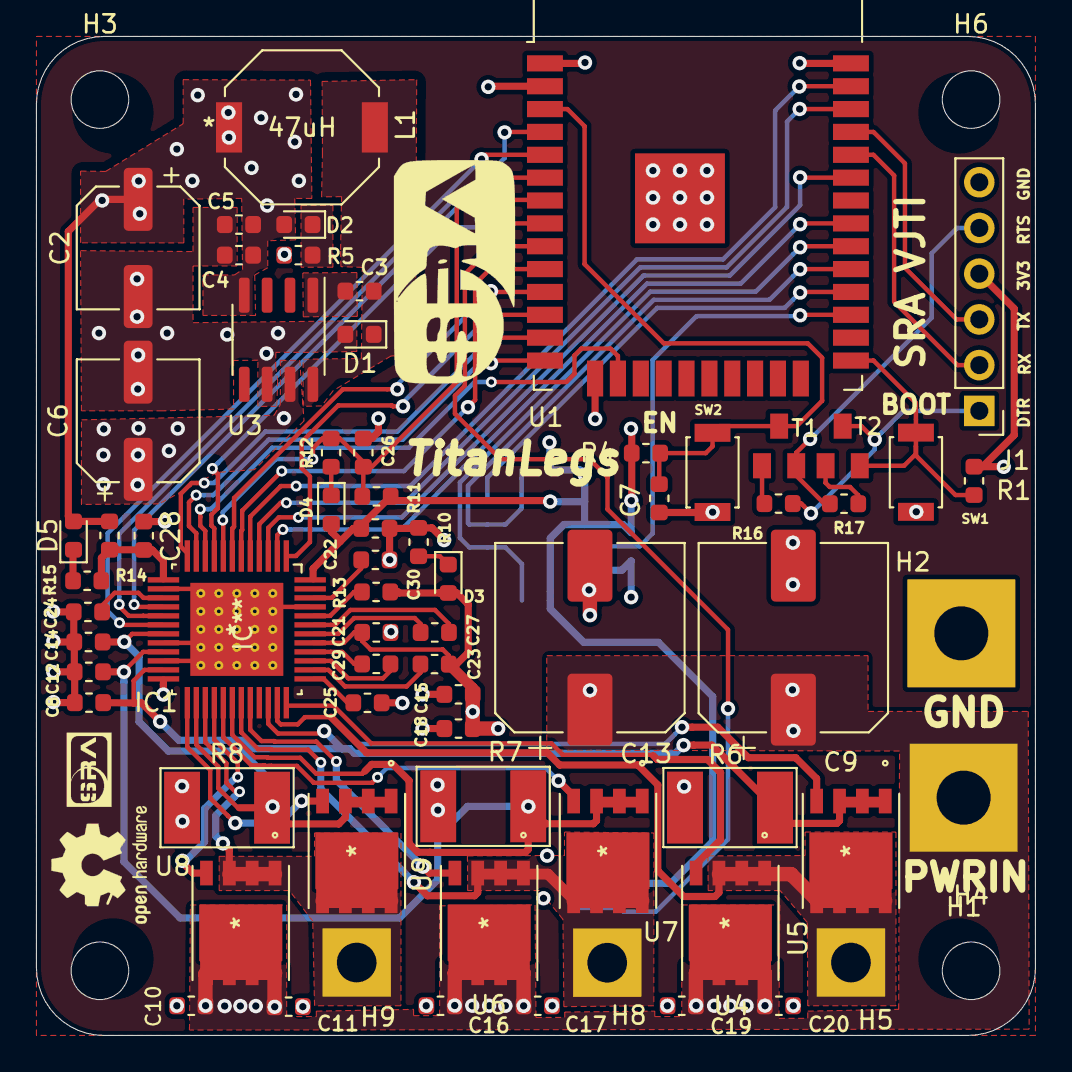
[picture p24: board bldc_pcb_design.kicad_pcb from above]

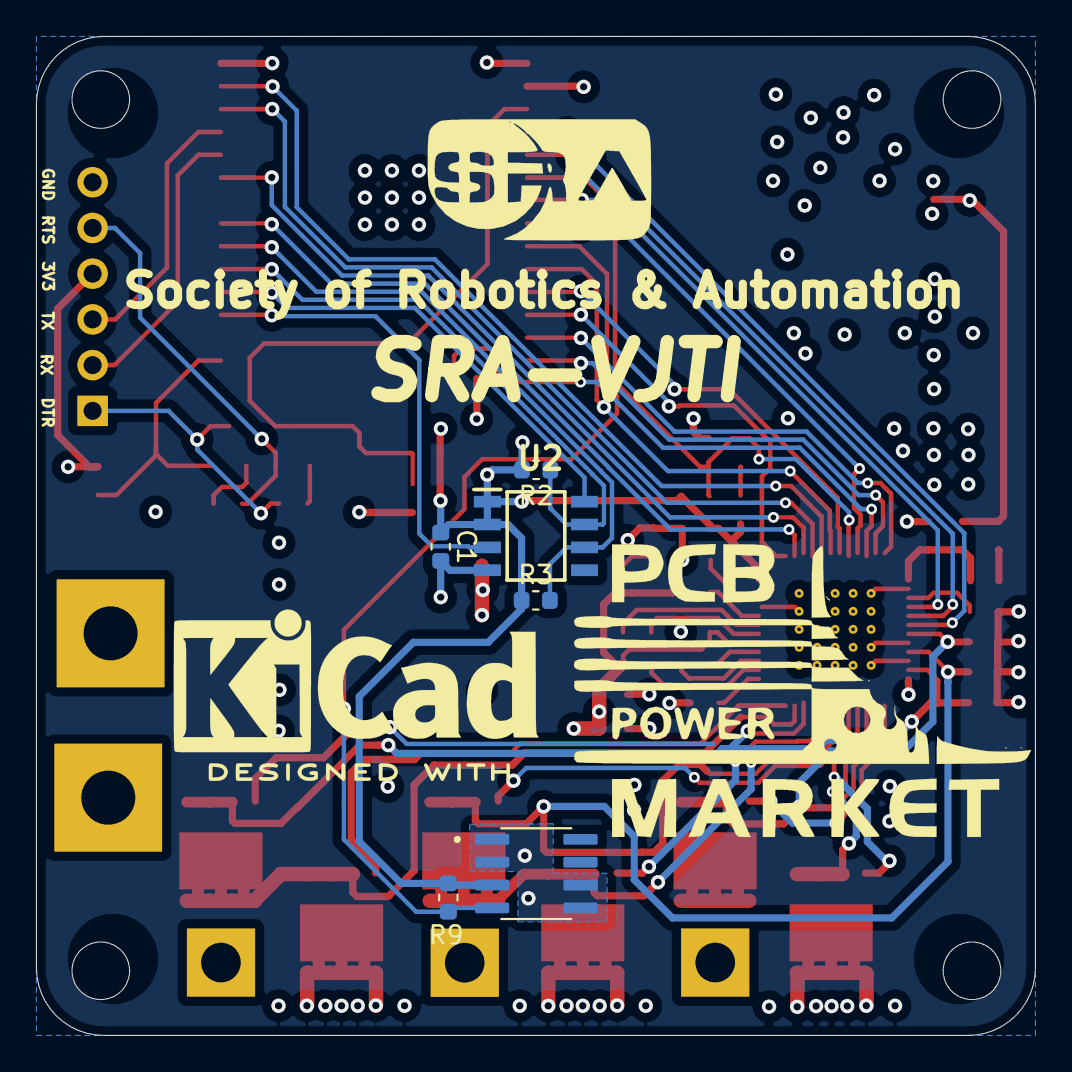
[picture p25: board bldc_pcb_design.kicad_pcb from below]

Board: 4 copper layers, 55.5 x 55.5 mm, 78 parts (6 on the bottom side), 59 nets.

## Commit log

2021-06-24 Updates in Gearbox Design (#1)
    * Mechanical Design
    * Revert "Mechanical Design"
    This reverts commit 3625ce9c8420bc28083b0ad78ce3180cb9b17e8c.
    * Assets
    * Create README.md
    * Update README.md
    * Update README.md
    * Update README.md
    * Design changes
    * Update README.md
2021-07-31 Added PCB schematics, assets and datasheets
2021-07-31 Added PCB schematics, assets and datasheets-2
    [DRV8305NPHPR.stl, DRV8305NPHPR.stp, bldc_pcb_design.kicad_pcb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]
2021-08-23 Started schematics design from scratch
    [DRV8305NPHPR.stl, DRV8305NPHPR.stp, bldc_pcb_design.sch]
2021-08-23 Completed schematics of ESP32 and Encoder
    [AS5600-ASOT.stp, bldc_pcb_design.sch]
2021-09-02 WIP: Added Switching mode regulator schematics
    [bldc_pcb_design.sch]
2021-09-02 Added component values for buck converter
    [bldc_pcb_design.sch]
2021-09-07 Added schematics for DRV8305
    [CSD18532NQ5B.stp, bldc_pcb_design.sch]
2021-09-07 Added TI Mosfets and LEDS
    [bldc_pcb_design.sch]
2021-09-08 Modified GPIO connections
    [bldc_pcb_design.sch]
2021-09-15 [Temp sensor] Added DS18S20Z+ and modified schematics
    [AS6200.step, DS18S20Z_.step, bldc_pcb_design.kicad_pcb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]
2021-09-28 Changed pin connections: IO34- DRV_nFAULT; IO15- NC; IO33- TEMP_DQ
    [bldc_pcb_design.sch]
2021-10-04 Optimised Schematics
    [XT30PW-M.stp, bldc_pcb_design.sch]
2021-10-07 Added Motor connector pads, rectified connections
    [bldc_pcb_design.sch]
2021-10-27 Annotated components and assigned footprints
    [SS34.step, Tactile_Switch.STEP, bldc_pcb_design.kicad_pcb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]
2021-11-09 Replaced Xt connector with motor pads
    [bldc_pcb_design.kicad_pcb, bldc_pcb_design.sch]
2021-11-09 Added Leg Design
    [1_Lower_Limb_Connector.STL, 2_Upper_Limb_Connector.STL, 3_Lower_Limb.STL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]
2021-11-09 Added GearBox STLs
    [Combined_Box.STL, Mediator_out.STL, Motor_Cover.STL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]
2021-11-11 Rough placement of components done for Routing. PCB Diameter : 78mm Circular
    [bldc_pcb_design.kicad_pcb]
2021-11-11 Generated bldc_pcb_design.net Netlist file
2021-11-11 Modified Part Tolerances
    [Combined_Box.STL, Mediator_out.STL, New_Shaft_1.STL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]
2022-01-05 Routing Iteration 1 done, Rectified schematics (SOx and shunt resistor connections)
    [8D43.step, bldc_pcb_design.kicad_pcb, bldc_pcb_design.sch]
2022-01-11 Made routing changes and optimized schematics, pcbnew
    [bldc_pcb_design.kicad_pcb, bldc_pcb_design.sch]
2022-01-11 Minor Silkscreen changes
    [bldc_pcb_design.kicad_pcb]
2022-01-14 Routed buck converter LM2672 by copper fills - FCu
    [bldc_pcb_design.kicad_pcb]
2022-01-20 Re-routed DRV8305 using corrected underneath GND pad footprint, back mounted Temp sensor
    [BC847.step, DRV8305NPHPR.stp, bldc_pcb_design.kicad_pcb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]
2022-01-20 Assigned common GND net to DRV8305's Central GND pad - PTH Holed Vias
    [bldc_pcb_design.kicad_pcb]
2022-01-21 Temp Sensor - Modified BCu Exposed Cu, B.Paste for better alignment
    [bldc_pcb_design.kicad_pcb]
2022-01-21 Modified SilkScreen
    [bldc_pcb_design.kicad_pcb]

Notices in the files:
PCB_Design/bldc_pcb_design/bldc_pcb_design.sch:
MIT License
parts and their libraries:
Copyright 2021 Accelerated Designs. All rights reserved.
